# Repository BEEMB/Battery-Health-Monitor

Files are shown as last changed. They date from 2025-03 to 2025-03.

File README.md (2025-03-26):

# Battery Health Monitor

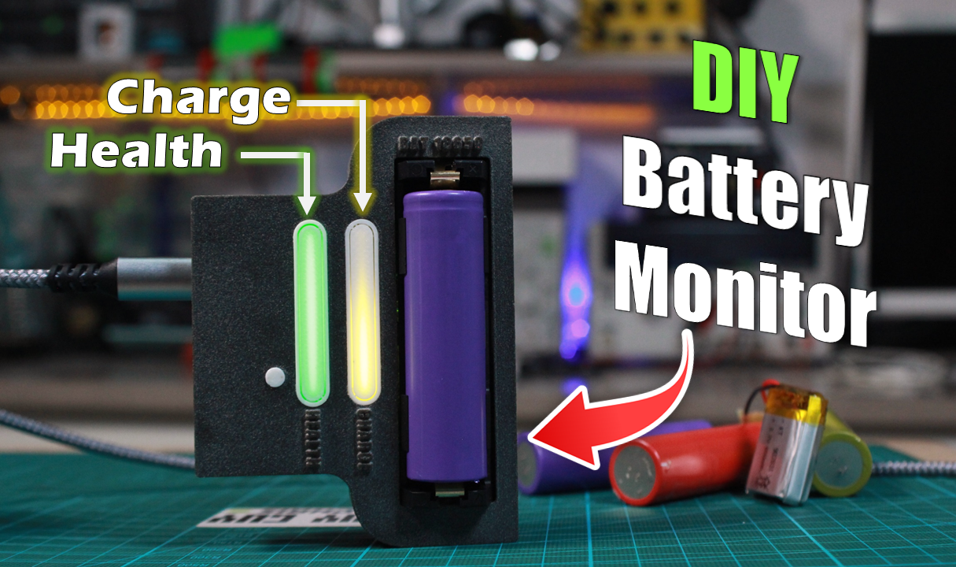
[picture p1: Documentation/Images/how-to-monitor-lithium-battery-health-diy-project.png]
How to Monitor Lithium Battery Health (https://youtu.be/RCJagutQ1Ck)


A DIY project to monitor State of Charge (SoC) and State of Health (SoH)...
This project is a compact device for monitoring the **State of Health (SoH)** and **State of Charge (SoC)** of lithium batteries. It uses the BQ27441 fuel gauge IC and BQ24075 charger IC, along with an ATmega328P microcontroller, to provide real-time battery data and display it through LED bars.

## Features
- Real-time monitoring of battery State of Health (SoH) and State of Charge (SoC).
- LED indicators for SoH and SoC.
- USB-C compatibility for charging and power input.
- Multiple battery connection options (18650 holder, JST connector, screw terminal).
- Compact and self-contained design.

## Hardware
- **Schematic**: [Schematic Charging Circuit.pdf](Hardware/Schematic/Schematic%20Charging%20Circuit.pdf) | [Schematic MCU Circuit.pdf](Hardware/Schematic/Schematic%20MCU%20Circuit.pdf)
- **Bill of Materials**: [BOM_Battery health device.xlsx](Hardware/BOM/BOM_Battery%20health%20device.xlsx)
- **Gerber Files**: [Gerber_Files/](Hardware/Gerber_Files/)
- **Pick and Place File**: [PickAndPlace_PCB_Battery-health-device.xlsx](Hardware/Pick_and_Place/PickAndPlace_PCB_Battery-health-device.xlsx)
- **3D Models**: [3D_Models/](Hardware/3D_Models/)

## Firmware
- **Arduino Code**: [Battery_health.ino](Firmware/Battery_health.ino)

## Assembly Guide
For step-by-step assembly instructions, refer to the [Assembly Guide](Documentation/Assembly_Guide.md).

## License
This project is licensed under the MIT License. See the [LICENSE](LICENSE) file for details.

## Video Demonstration
Watch the video demonstration of this project on [YouTube](https://www.youtube.com/watch?v=RCJagutQ1Ck).

## Credits
- Inspired by SparkFun's [Battery Babysitter](https://www.sparkfun.com/sparkfun-battery-babysitter-lipo-battery-manager.html).
- Designed and built by [DIY GUY Chris](https://github.com/BEEMB).

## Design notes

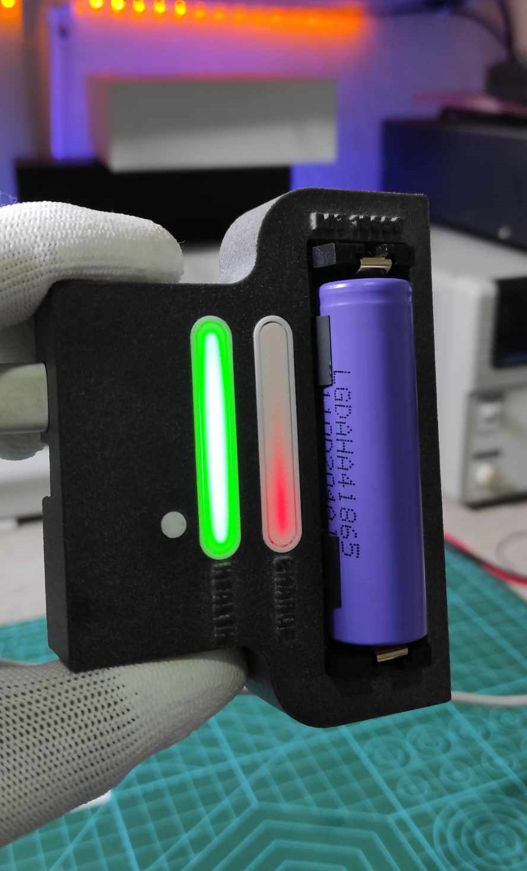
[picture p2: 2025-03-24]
Documentation/Images/Battery charging phase.jpg

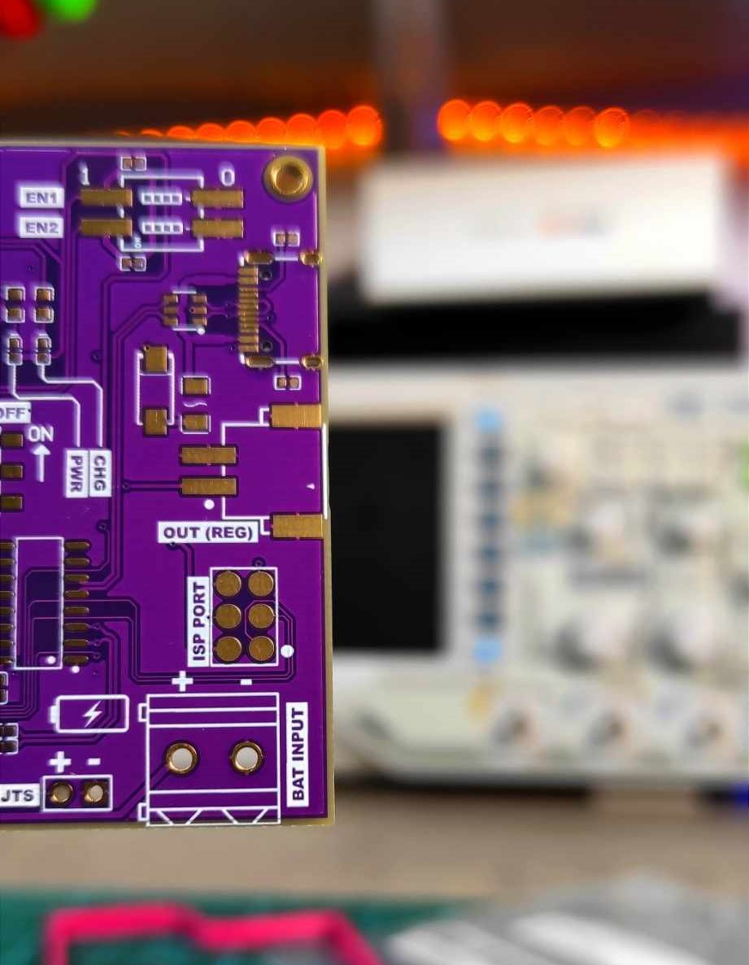
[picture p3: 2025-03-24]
Documentation/Images/ISP Port.jpg

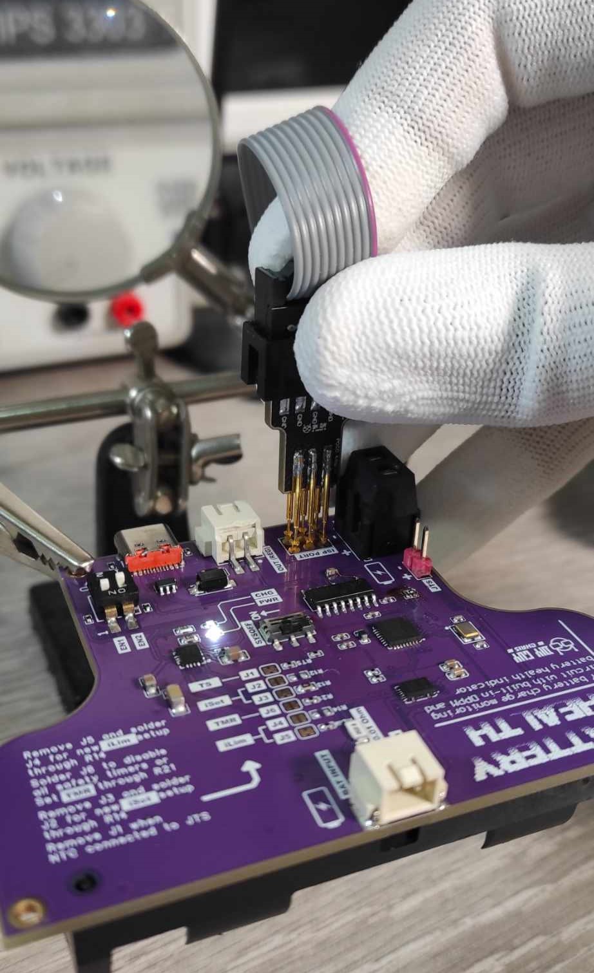
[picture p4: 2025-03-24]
Documentation/Images/ISP Programming.jpg

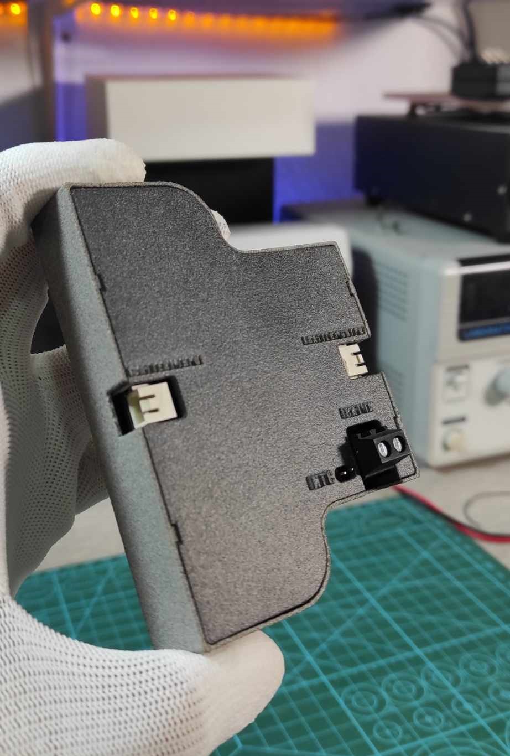
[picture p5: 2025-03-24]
Documentation/Images/JST Connectors.jpg

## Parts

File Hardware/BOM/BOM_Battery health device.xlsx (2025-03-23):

No. | Quantity | Comment | Designator | Footprint | Value | Manufacturer Part | Manufacturer | Supplier Part | Supplier
1 | 1 | BH-18650-B1BA002 | BT1 | BATTERY-SMD_18650-1S-L77.1-W20.7-1 |  | BH-18650-B1BA002 | MYOUNG(美阳) | C2988620 | LCSC
2 | 1 | 1uF | C1 | C1206 |  | CL31B105KAHNNNE | SAMSUNG(三星) | C28322 | LCSC
3 | 2 | 10uF | C2,C3 | C0805 |  | CS2012X7R106K100NRE | SAMWHA(三和) | C1222438 | LCSC
4 | 1 | 470nF | C4 | C0603 |  | CL10B474KA8NNNC | SAMSUNG(三星) | C1623 | LCSC
5 | 1 | 1uF | C5 | C0603 |  | 0603B105K250NT | FH(风华) | C59302 | LCSC
6 | 2 | 22pF | C6,C7 | C0402 |  | 0402CG220J500NT | FH | C1555 | LCSC
7 | 11 | 100nF | C8,C9,C11,C12,C13,C14,C15,C16,C17,C18,C19 | C0402 |  | CL05B104KO5NNNC | SAMSUNG(三星) | C1525 | LCSC
8 | 1 | 100nF | C10 | C0402 |  | CC0402KRX7R6BB104 | YAGEO(国巨) | C309458 | LCSC
9 | 1 | 100nF | C20 | C0402 | 100nF | CL05B104KO5NNNC | SAMSUNG(三星) | C1525 | LCSC
10 | 2 | HC-HA-2AWT | CN1,CN2 | CONN-SMD_2P-P2.50_HCTL_HC-HA-2AWT |  | HC-HA-2AWT | HCTL(华灿天禄) | C2845727 | LCSC
11 | 1 | USBLC6-2SC6 | D1 | SOT-23-6_L2.9-W1.6-P0.95-LS2.8-BL |  | USBLC6-2SC6 | ST(意法半导体) | C7519 | LCSC
12 | 1 | SS14_C266551 | D2 | SMA_L4.4-W2.8-LS5.4-RD |  | SS14 | BORN(伯恩半导体) | C266551 | LCSC
13 | 1 | ASMD1206-050 | F1 | F1206 |  | ASMD1206-050 | JDTfuse(集电通) | C135338 | LCSC
14 | 3 | Cut jumper | J1,J3,J5 | CUT_JMPR
15 | 3 | CUT JUMPER NO (DIF) | J2,J4,J6 | CUT_JMPR_NO_DIF
16 | 1 | HDR-M-2.54_2x3 | J7 | HDR-M-2.54_2X3 |  |  |  | C65114 | LCSC
17 | 1 | HDR-M-2.54_1x2 | JTS | HDR-M-2.54_1X2 |  |  |  | C124375 | LCSC
18 | 1 | 10uH | L1 | L0603 |  | CPY160808T-100M-NP | chilisin(奇力新) | C285968 | LCSC
19 | 2 | FC-F1005UGK-520M5 | LED1,LED2 | LED0402-RD |  | NCD0402G1 | 国星光电 | C130723 | LCSC
20 | 2 | FC-F1005HOK-600H5 | LED3,LED4 | LED0402-R-RD |  | NCD0402O1 | 国星光电 | C130720 | LCSC
21 | 3 | 10kΩ | R1,R4,RTS | R0402 |  | RE0402FRE0710KL | YAGEO(国巨) | C723523 | LCSC
22 | 2 | 4.7KΩ | R5,R6 | R0402 |  | RTT024704FTH | RALEC(旺诠) | C159024 | LCSC
23 | 2 | 1kΩ | R7,R9 | R0603 |  | 0603WAF1001T5E | UNI-ROYAL(厚声) | C21190 | LCSC
24 | 2 | 100kΩ | R8,R11 | R0402 |  | RC0402FR-7W100KL | YAGEO(国巨) | C606167 | LCSC
25 | 1 | 0.01OHM(1206) | R10 | RESISTOR 150 OHM (1206) |  | New SchematicLib
26 | 2 | 0Ω | R12,R14 | R0603 |  | RC0603JR-070RL | YAGEO(国巨) | C95177 | LCSC
27 | 1 | 590Ω | R13 | R0603 |  | CR0603F590RP05Z | EVER OHMS(天二科技) | C245050 | LCSC
28 | 2 | 5.1kΩ | R15,R16 | R0402 |  | 0402WGF5101TCE | UNI-ROYAL(厚声) | C25905 | LCSC
29 | 4 | 1kΩ | R17,R18,R19,R20 | R0402 |  | RC-02W1001FT | FH(风华) | C226166 | LCSC
30 | 1 | 20kΩ | R21 | R0402 |  | 0402WGF2002TCE | UNI-ROYAL(厚声) | C25765 | LCSC
31 | 1 | 1.1kΩ | RLIM | R0402 |  | RMC04021.1K1%N | Tyohm(幸亚电阻) | C325543 | LCSC
32 | 1 | HAD-02HWA-R | SW1 | SW-SMD_HAD-02HWA-R |  | HAD-02HWA-R | ReliaPro | C4669 | LCSC
33 | 1 | MS-22C01-G010 | SW2 | SW-SMD_6P-L7.2-W3.5-P2.50-LS6.0-TL |  | MS-22C01-G010 | G-Switch(品赞) | C2837066 | LCSC
34 | 1 | DB128L-5.0-2P-BK-S | U1 | CONN-TH_2P-P5.00_DB128L-5.0-2P-BK-S |  | DB128L-5.0-2P-BK-S | DORABO(地博电气) | C430597 | LCSC
35 | 1 | BQ27441DRZR-G1B | U2 | SON-12_L4.0-W2.5-P0.40-BL-EP |  | BQ27441DRZR-G1B | TI(德州仪器) | C473374 | LCSC
36 | 1 | BQ24075RGTR | U3 | QFN-16_L3.0-W3.0-P0.50-TL-EP1.7 |  | BQ24075RGTR | TI(德州仪器) | C15464 | LCSC
37 | 1 | ATMEGA328P-MU | U4 | QFN-32_L5.0-W5.0-P0.50-BL-EP3.4 |  | ATMEGA328P-MU | MICROCHIP | C38896 | LCSC
38 | 1 | CH340C | U5 | SOP-16_L10.0-W3.9-P1.27-LS6.0-BL |  | CH340C | WCH(南京沁恒) | C84681 | LCSC
39 | 20 | XL-1010RGBC-WS2812B | U6,U7,U8,U9,U10,U11,U12,U13,U14,U15,U16,U17,U18,U19,U20,U21,U22,U23,U24,U25 | LED-SMD_4P-L1.0-W1.0-TL_XL-1010RGBC-WS2812B |  | XL-1010RGBC-WS2812B | XINGLIGHT(成兴光) | C5349953 | LCSC
40 | 1 | TYPEC-304-BCP16 | USB2 | USB-C-SMD_TYPEC-304-BCP16 |  | TYPEC-304-BCP16 | XUNPU(讯普) | C720629 | LCSC
41 | 1 | 16MHz | X1 | OSC-SMD_4P-L3.2-W2.5-BL |  | X322516MLB4SI | YXC | C13738 | LCSC

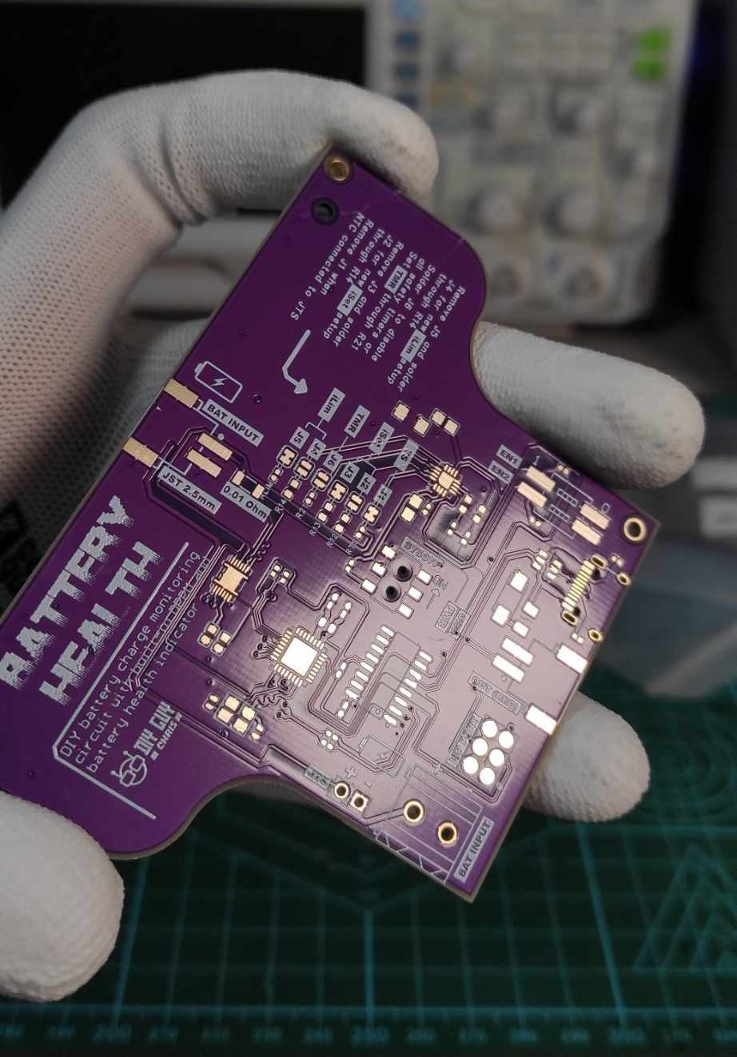
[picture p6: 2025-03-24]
Documentation/Images/Ordered PCB.jpg

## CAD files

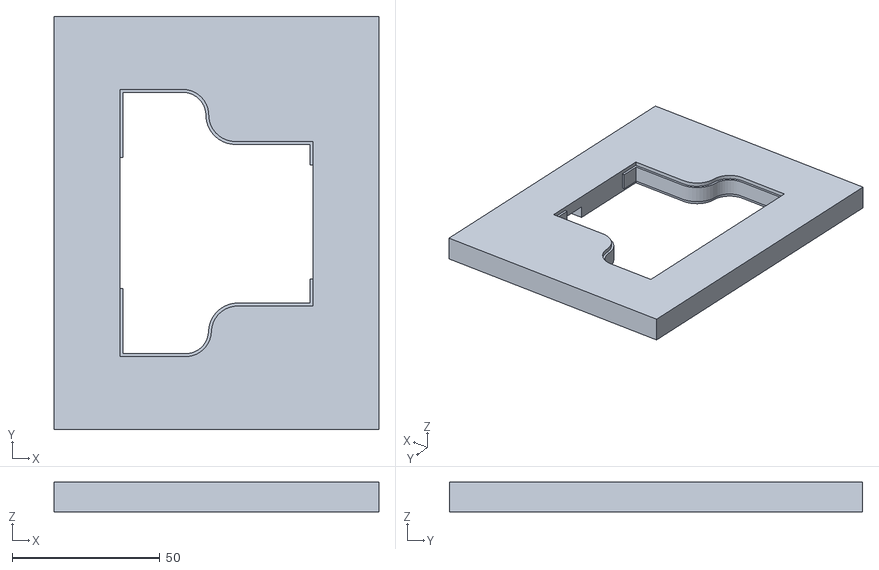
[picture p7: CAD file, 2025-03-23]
Hardware/3D_Models/SMT Assembly support.STL
110.0 x 140.0 x 10.0

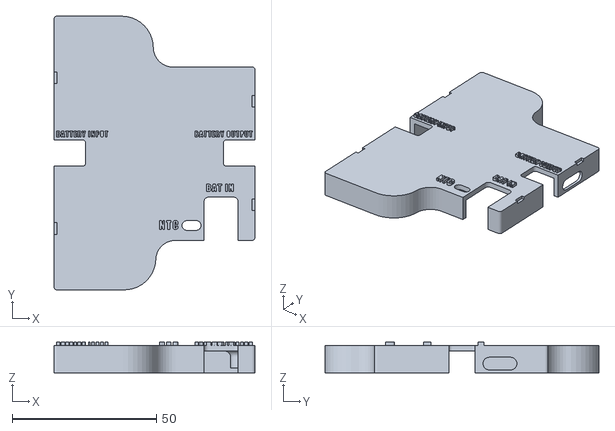
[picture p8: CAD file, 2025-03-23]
Hardware/3D_Models/Battery Health housing bottom.STL
69.7 x 95.0 x 10.6

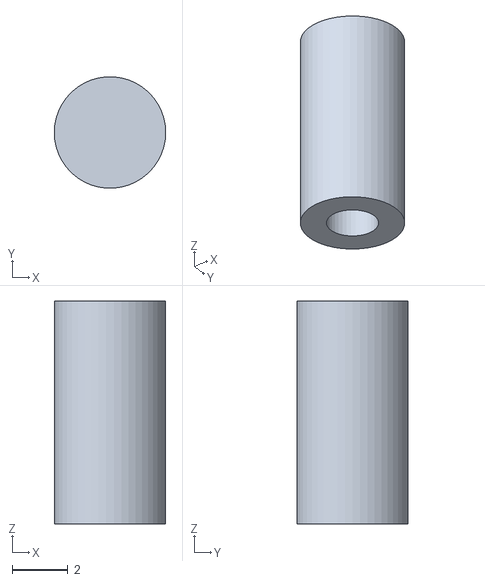
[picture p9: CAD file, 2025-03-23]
Hardware/3D_Models/TxRxCover.STL
4.00 x 3.99 x 8.00

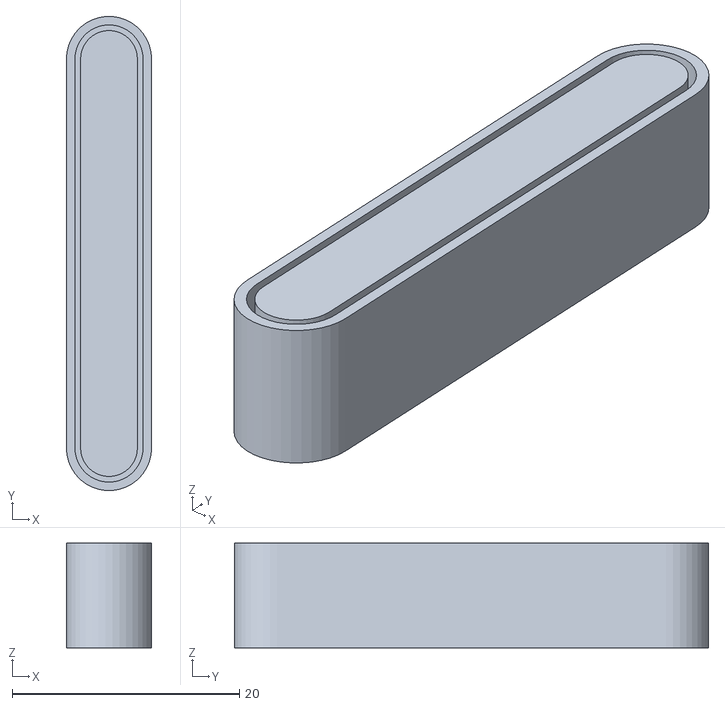
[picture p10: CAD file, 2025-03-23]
Hardware/3D_Models/LED Cover.STL
7.50 x 41.7 x 9.20

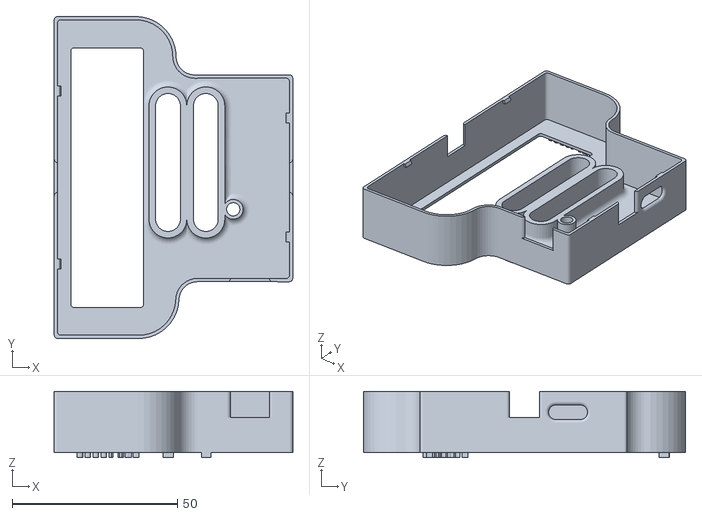
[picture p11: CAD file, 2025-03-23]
Hardware/3D_Models/Battery Health housing top.STL
72.1 x 97.4 x 20.0

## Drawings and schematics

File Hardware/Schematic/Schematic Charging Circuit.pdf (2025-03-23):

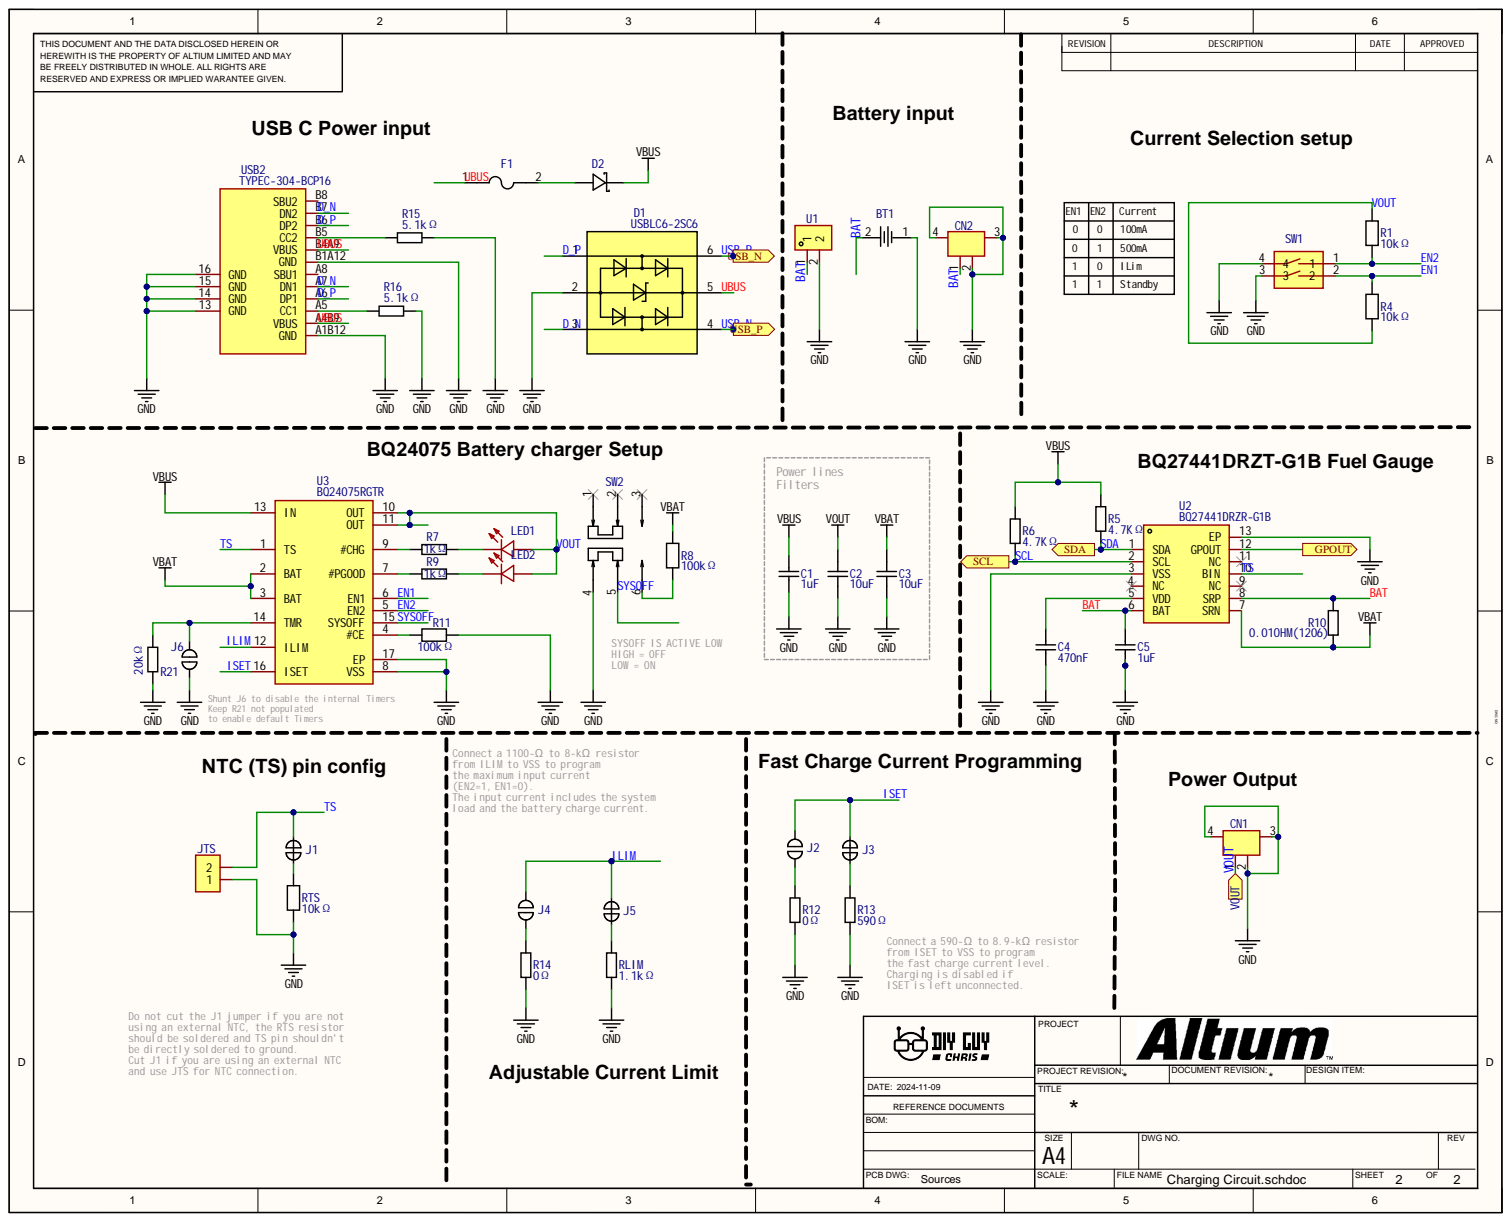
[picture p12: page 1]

THIS DOCUMENT AND THE DATA DISCLOSED HEREIN OR HEREWITH IS THE PROPERTY OF ALTIUM LIMITED AND MAY BE FREELY DISTRIBUTED IN WHOLE. ALL RIGHTS ARE RESERVED AND EXPRESS OR IMPLIED WARANTEE GIVEN. | | | | REVISION | DESCRIPTION | DATE | APPROVED

EN1 | EN2 | Current
0 | 0 | 100mA

SYSOFF IS ACTIVE LOW
HIGH = OFF
LOW = ON

Shunt J6 to disable the internal Timers
Keep R21 not populated
to enable default Timers
GND

Connect a 1100-Ω to 8-kΩ resistor
from ILIM to VSS to program
the maximum input current
The input current includes the system
load and the battery charge current.

Connect a 590-Ω to 8.9-kΩ resistor
from ISET to VSS to program
the fast charge current level.
Charging is disabled if ISET is left unconnected.

Do not cut the J1 jumper if you are not using an external NTC, the RTS resistor

PROJECT

should be soldered and TS pin shouldn't
be directly soldered to ground.
Cut J1 if you are using an external NTC and use JTS for NTC connection.

PROJECT REVISION: | DOCUMENT REVISION: * | DESIGN ITEM: *

SIZE A4 | | DWG NO. | REV

PCB DWG: Sources | SCALE: | FILE NAME Charging Circuit.schdoc | SHEET OF 2 2

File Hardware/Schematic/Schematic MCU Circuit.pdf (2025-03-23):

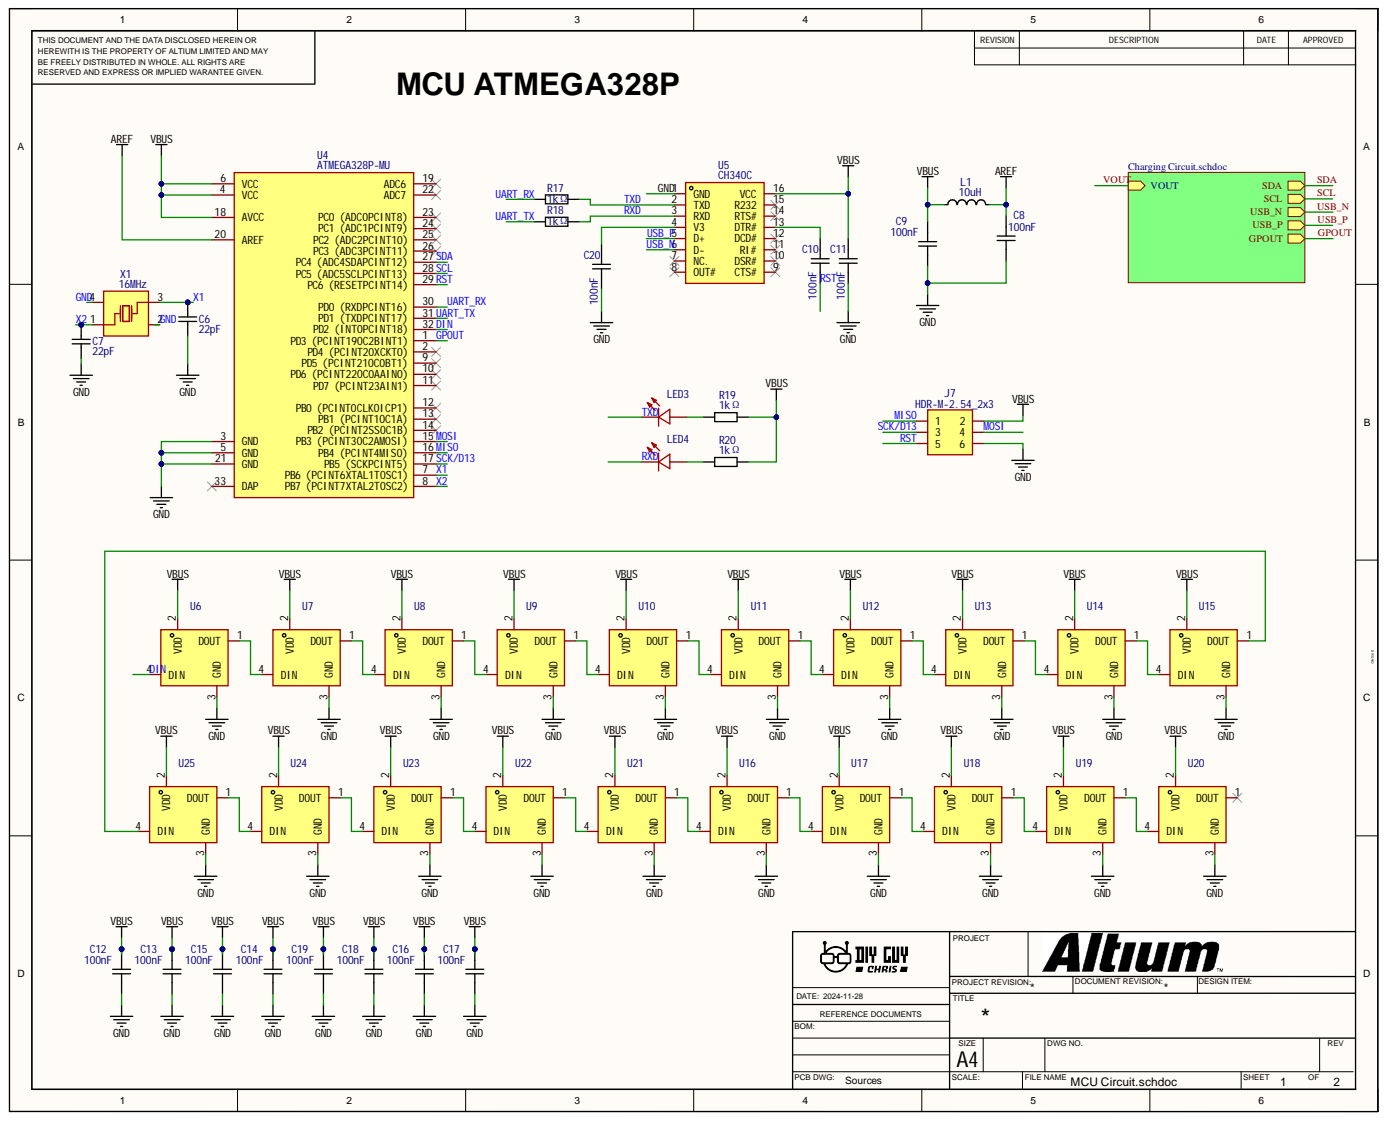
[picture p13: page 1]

THIS DOCUMENT AND THE DATA DISCLOSED HEREIN OR HEREWITH IS THE PROPERTY OF ALTIUM LIMITED AND MAY BE FREELY DISTRIBUTED IN WHOLE. ALL RIGHTS ARE RESERVED AND EXPRESS OR IMPLIED WARANTEE GIVEN. | MCU ATMEGA328P | REVISION | DESCRIPTION | DATE | APPROVED

PROJECT

PROJECT REVISION: | DOCUMENT REVISION: * | DESIGN ITEM: *

SIZE A4 | | DWG NO. | REV

PCB DWG: Sources | SCALE: | FILE NAME MCU Circuit.schdoc | SHEET OF 1 2

Comment | Description | Designator | Footprint | LibRef | Quantity
BH-18650-B1BA002 | | BT1 | BATTERY-SMD_18650-1S-L77.1-W20.7-1 | BH-18650-B1BA002 | 1
1uF | | C1 | C1206 | 1uF | 1
10uF | | C2, C3 | C0805 | 10uF | 2
470nF | | C4 | C0603 | 470nF | 1
1uF | | C5 | C0603 | 1uF | 1
22pF | | C6, C7 | C0402 | 22pF | 2
100nF | | C8, C9, C10, C11, C12, C13, C14, C15, C16, C17, C18, C19, C20 | C0402 | 100nF | 13
HC-HA-2AWT | | CN1, CN2 | CONN-SMD_2P-P2.50_HCTL_HC-HA-2AWT | HC-HA-2AWT | 2
USBLC6-2SC6 | | D1 | SOT-23-6_L2.9-W1.6-P0.95-LS2.8-BL | USBLC6-2SC6 | 1
SS14_C266551 | | D2 | SMA_L4.4-W2.8-LS5.4-RD | SS14_C266551 | 1
ASMD1206-050 | | F1 | F1206 | ASMD1206-050 | 1
Cut jumper | | J1, J3, J5 | | Cut jumper | 3
CUT JUMPER NO (DIF) | | J2, J4, J6 | | CUT JUMPER NO (DIF) | 3
HDR-M-2.54_2x3 | | J7 | HDR-M-2.54_2X3 | HDR-M-2.54_2x3 | 1
HDR-M-2.54_1x2 | | JTS | HDR-M-2.54_1X2 | HDR-M-2.54_1x2 | 1
10uH | | L1 | L0603 | 10uH | 1
FC-F1005UGK-520M5 | | LED1, LED2 | LED0402-RD | FC-F1005UGK-520M5 | 2
FC-F1005HOK-600H5 | | LED3, LED4 | LED0402-R-RD | FC-F1005HOK-600H5 | 2
10kΩ | | R1, R4, RTS | R0402 | 10kΩ | 3
4.7KΩ | | R5, R6 | R0402 | 4.7KΩ | 2
1kΩ | | R7, R9 | R0603 | 1kΩ | 2
100kΩ | | R8, R11 | R0402 | 100kΩ | 2
0.01OHM(1206) | | R10 | | 0.01OHM(1206) | 1
0Ω | | R12, R14 | R0603 | 0Ω | 2
590Ω | | R13 | R0603 | 590Ω | 1
5.1kΩ | | R15, R16 | R0402 | 5.1kΩ | 2
1kΩ | | R17, R18, R19, R20 | R0402 | 1kΩ | 4
20kΩ | | R21 | R0402 | 20kΩ | 1
1.1kΩ | | RLIM | R0402 | 1.1kΩ | 1
HAD-02HWA-R | | SW1 | SW-SMD_HAD-02HWA-R | HAD-02HWA-R | 1
MS-22C01-G010 | | SW2 | SW-SMD_6P-L7.2-W3.5-P2.50-LS6.0-TL | MS-22C01-G010 | 1
DB128L-5.0-2P-BK-S | | U1 | CONN-TH_2P-P5.00_DB128L-5.0-2P-BK-S | DB128L-5.0-2P-BK-S | 1
BQ27441DRZR-G1B | | U2 | SON-12_L4.0-W2.5-P0.40-BL-EP | BQ27441DRZR-G1B | 1
BQ24075RGTR | | U3 | QFN-16_L3.0-W3.0-P0.50-TL-EP1.7 | BQ24075RGTR | 1
ATMEGA328P-MU | | U4 | QFN-32_L5.0-W5.0-P0.50-BL-EP3.4 | ATMEGA328P-MU | 1
CH340C | | U5 | SOP-16_L10.0-W3.9-P1.27-LS6.0-BL | CH340C | 1
XL-1010RGBC-WS2812B | | U6, U7, U8, U9, U10, U11, U12, U13, U14, U15, U16, U17, U18, U19, U20, U21, U22, U23, U24, U25 | LED-SMD_4P-L1.0-W1.0-TL_XL-1010RGBC-WS2812B | XL-1010RGBC-WS2812B | 20
TYPEC-304-BCP16 | | USB2 | USB-C-SMD_TYPEC-304-BCP16 | TYPEC-304-BCP16 | 1
16MHz | | X1 | OSC-SMD_4P-L3.2-W2.5-BL | 16MHz | 1

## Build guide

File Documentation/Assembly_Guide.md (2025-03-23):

# Assembly Guide

## 1. PCB Assembly
1. Solder all surface-mount components using the provided Gerber files and BOM.
2. Use the Pick and Place file for component placement.
3. Double-check solder joints, especially for the USB-C connector and microcontroller.

## 2. 3D-Printed Housing
1. Print the STL files from the `3D_Models/` folder.
2. Assemble the housing using the provided screws and inserts.

## 3. Firmware Flashing
1. Upload the `Battery_health.ino` sketch to the ATmega328P microcontroller using an Arduino IDE.
2. Connect the device to a battery and power source to test functionality.

## 4. Testing
1. Connect a lithium battery to the device.
2. Verify that the LED bars display the correct State of Charge (SoC) and State of Health (SoH).
3. Use the serial monitor to check detailed battery data.

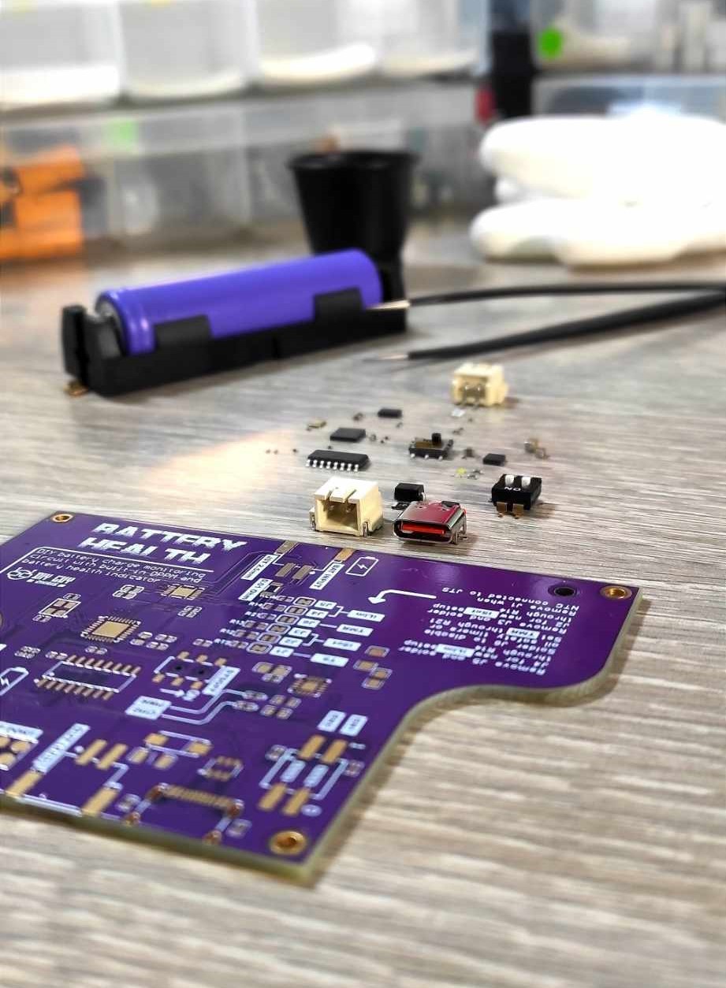
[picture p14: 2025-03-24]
Documentation/Images/Assembly setup.jpg

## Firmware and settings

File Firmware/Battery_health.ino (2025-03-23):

#include <SparkFunBQ27441.h>
#include <Adafruit_NeoPixel.h>

// Constants
#define DATAPIN            2       // Pin connected to the NeoPixel data input
#define NUMPIXELS          20      // Number of NeoPixels in the LED bar
#define BATTERY_CAPACITY   1300    // Battery full capacity (mAh) - adjust based on your battery
#define SERIAL_BAUD_RATE   115200  // Serial communication baud rate

// NeoPixel object
Adafruit_NeoPixel BARS = Adafruit_NeoPixel(NUMPIXELS, DATAPIN, NEO_GRB + NEO_KHZ800);

// Global variables
unsigned int Charge = 0;           // Battery State of Charge (SoC)
unsigned int health = 0;           // Battery State of Health (SoH)
unsigned int PreviousCharge = 0;   // Previous SoC value for comparison
int R_SOC = 0, G_SOC = 0, B_SOC = 0; // RGB values for SoC LED bar
int R_SOH = 0, G_SOH = 0, B_SOH = 0; // RGB values for SoH LED bar

// Function to initialize the BQ27441 fuel gauge
void InitBQ27441() {
  if (!lipo.begin()) { // Initialize communication with the BQ27441 IC
    Serial.println("Error: Unable to communicate with BQ27441.");
    Serial.println("Check wiring and try again.");
    delay(500);
    while (1); // Halt if communication fails
  }
  Serial.println("Successfully Connected to BQ27441!");
  Serial.println("SOC | voltage | current | capacity | power | SOH");
  lipo.setCapacity(BATTERY_CAPACITY); // Set battery capacity
}

// Function to log battery data
void BatteryDataLogging() {
  // Get battery data from BQ27441
  unsigned int volts = lipo.voltage();             // Battery voltage (mV)
  int current = lipo.current(AVG);                 // Average current (mA)
  unsigned int fullCapacity = lipo.capacity(FULL); // Full capacity (mAh)
  unsigned int capacity = lipo.capacity(REMAIN);   // Remaining capacity (mAh)
  int power = lipo.power();                        // Average power draw (mW)
  health = lipo.soh();                             // State of Health (SoH)

  // Print battery data to Serial Monitor
  String toPrint = String(Charge) + "%   | ";
  toPrint += String(volts) + " mV | ";
  toPrint += String(current) + " mA | ";
  toPrint += String(capacity) + " / ";
  toPrint += String(fullCapacity) + " mAh | ";
  toPrint += String(power) + " mW | ";
  toPrint += String(health) + "%";
  Serial.println(toPrint);
}

// Function to set LED bar color based on a parameter (SoC or SoH)
void BarsColor(unsigned int parameter, int* r, int* g, int* b) {
  if (parameter > 0 && parameter < 20) {
    *r = 100; *g = 0; *b = 0;    // Red for low values
  } else if (parameter >= 20 && parameter < 40) {
    *r = 100; *g = 8; *b = 0;    // Orange for medium-low values
  } else if (parameter >= 40 && parameter < 60) {
    *r = 100; *g = 90; *b = 0;   // Yellow for medium values
  } else if (parameter >= 60 && parameter < 80) {
    *r = 28; *g = 100; *b = 0;   // Light green for medium-high values
  } else if (parameter >= 80 && parameter <= 100) {
    *r = 0; *g = 100; *b = 0;    // Green for high values
  }
}

// Function to update the State of Health (SoH) LED bar
void SOHLedBarsIndicators() {
  BatteryDataLogging(); // Log battery data
  BarsColor(health, &R_SOH, &G_SOH, &B_SOH); // Set color based on SoH

  // Update LED bar for SoH
  for (int i = 20 - (health / 10); i < NUMPIXELS; i++) {
    BARS.setPixelColor(i, BARS.Color(R_SOH, G_SOH, B_SOH));
    delay(2);
  }

  // Handle partial segments (e.g., 23% -> 2 full LEDs + 1 partial LED)
  if ((health % 10) != 0) {
    int partialPixel = 20 - (health / 10) - 1;
    int brightnessFactor = 20 - (2 * (health % 10));
    BARS.setPixelColor(partialPixel, BARS.Color(R_SOH / brightnessFactor, G_SOH / brightnessFactor, B_SOH / brightnessFactor));
    delay(2);
  }
  BARS.show(); // Update the LED bar
}

// Function to update the State of Charge (SoC) LED bar
void SOCLedBarsIndicators() {
  Charge = lipo.soc(); // Get current State of Charge (SoC)

  // Update LED bar only if SoC has changed
  if (Charge != PreviousCharge) {
    PreviousCharge = Charge;
    BatteryDataLogging(); // Log battery data
    BarsColor(Charge, &R_SOC, &G_SOC, &B_SOC); // Set color based on SoC

    // Clear the first 10 LEDs (SoC bar)
    for (int i = 0; i < 10; i++) {
      BARS.setPixelColor(i, BARS.Color(0, 0, 0));
      delay(1);
    }
    BARS.show();

    // Update LED bar for SoC
    for (int i = 0; i < Charge / 10; i++) {
      BARS.setPixelColor(i, BARS.Color(R_SOC, G_SOC, B_SOC));
      delay(1);
    }

    // Handle partial segments (e.g., 23% -> 2 full LEDs + 1 partial LED)
    if ((Charge % 10) != 0) {
      int partialPixel = Charge / 10;
      int brightnessFactor = 20 - (2 * (Charge % 10));
      BARS.setPixelColor(partialPixel, BARS.Color(R_SOC / brightnessFactor, G_SOC / brightnessFactor, B_SOC / brightnessFactor));
      delay(2);
    }
    BARS.show(); // Update the LED bar
  }
}

void setup() {
  Serial.begin(SERIAL_BAUD_RATE); // Initialize Serial communication
  BARS.begin(); // Initialize NeoPixel LED bar

  // Turn off all LEDs initially
  for (int i = 0; i < NUMPIXELS; i++) {
    BARS.setPixelColor(i, BARS.Color(0, 0, 0));
    delay(2);
  }
  BARS.show();

  InitBQ27441(); // Initialize BQ27441 fuel gauge
  delay(50);
  SOHLedBarsIndicators(); // Display initial SoH
}

void loop() {
  SOCLedBarsIndicators(); // Update SoC LED bar
  delay(100); // Small delay to reduce CPU usage
}

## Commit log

2025-03-23 Hardware/Gerber_Files/Gerber PCB Battery health device.rar
2025-03-23 Hardware/3D_Models/Battery Health housing bottom.STL
    [Battery Health housing bottom.STL]
2025-03-23 to Hardware/3D_Models/Battery Health housing top.STL
    [Battery Health housing top.STL]
2025-03-23 Hardware/3D_Models/LED Cover.STL
    [LED Cover.STL]
2025-03-23 Hardware/3D_Models/SMT Assembly support.STL
    Used to as solder paste aid
    [SMT Assembly support.STL]
2025-03-23 Hardware/BOM/BOM_Battery health device.xlsx
    [BOM_Battery health device.xlsx]
2025-03-23 Hardware/Schematic/Schematic Charging Circuit.pdf
2025-03-23 Hardware/Schematic/Schematic MCU Circuit.pdf
2025-03-23 Documentation/Images/Device final look.JPG
